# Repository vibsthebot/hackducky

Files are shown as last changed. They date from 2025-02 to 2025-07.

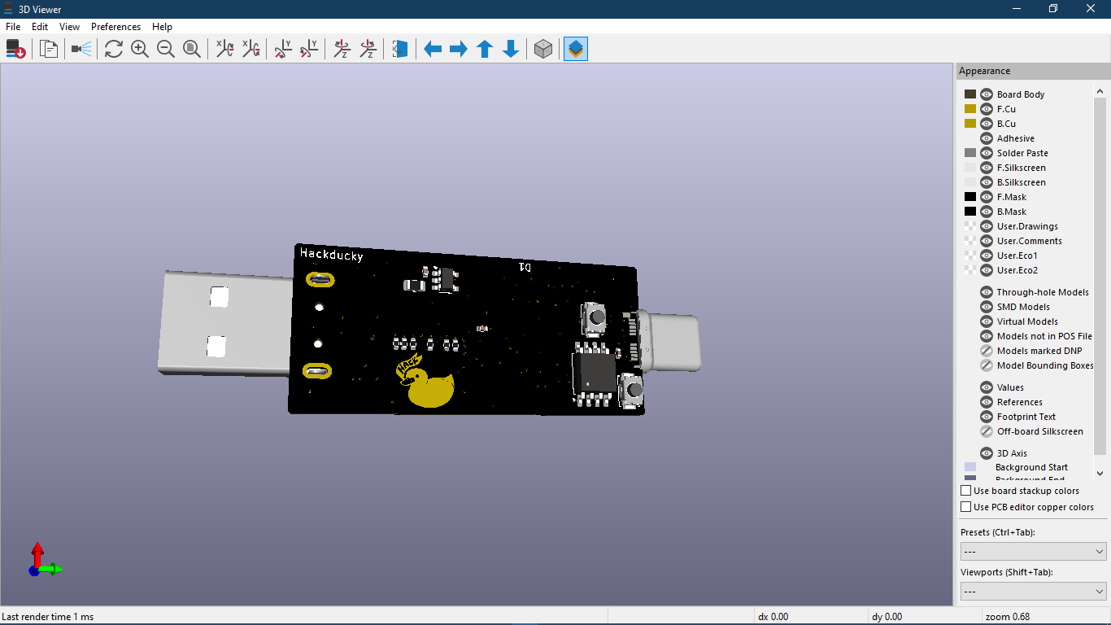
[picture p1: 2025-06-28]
pcb/v7/img/image.png

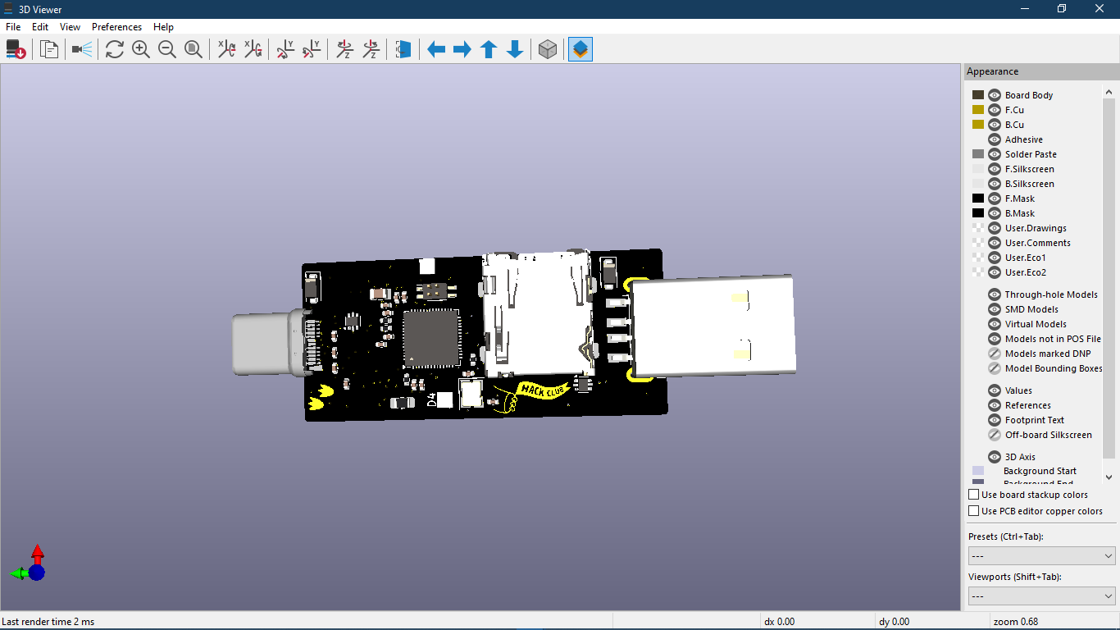
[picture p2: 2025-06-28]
pcb/v7/img/image-1.png

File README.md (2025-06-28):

# HackDucky - New YSWS!

The hackclub themed USB rubber ducky ! - Check out [hackducky](https://hackclub.slack.com/archives/C08B8HZBC85)

# What is this?

Hackducky is hackclubs own version of making a USB rubber ducky built by hackclubers.A usb rubber ducky is basically something that looks like a USB but is actually a trojan. It pretends to be a keyboard to the computer allowing you to basically take control of the computer you plug it into

## What you get

- Hackducky Board
    -  Dual USB ports (USB-A and USB-C)
    -  LED for the status - you can use it for other things if you like !
    -  Button for any extra features you may want to add !
    -  All duckyscripts are stored in the Hackduckys flash memory !

## Getting Started

1. - WIP

# Submission Criteria  

## 1. Time Requirement  
- **HackDucky Light:** Minimum of **3-4 hours** of development.  
- **HackDucky Pro:** Minimum of **5-6 hours** of development.  
- **Tracking:** Use **WakaTime** to track your development hours.  

## 2. Core Features (Must have 3)  
- Not just simple actions—core features should be impactful and unique.  
- **Examples:**  
  1. Open Notepad, start typing gibberish, and change the desktop background.  
  2. Open the terminal, run commands, and create pop-ups to scare the user.  
  3. Fake a system crash by downloading a **blue screen image** and freezing the mouse.  

## 3. Additional Features (Must have 5-7)  
- Include **at least 5-7 normal features** outside of the core features.  
- The more features, the better!  

## 4. Originality  
- Your project must be an **original idea** and not a direct copy from a tutorial.  
- Tutorials can be referenced, but your submission should be your own creation.  

## 5. Submission Limit  
- You can submit **multiple projects**, but you can only receive **one HackDucky** (either Pro or Light).  

## What the LED indicators mean

- Triple blink: Startup Sequence
- Single blink: Working/Processing - running/Starting Execution
- Rapid blinking: DuckyScript is incorrect / Firmware broke 😭 - Create a PR or new issue desribing the firmware problem

## Troubleshooting the LED's

1. LED rapidly blinking at startup:
 - Programming Mode
    - All is working great!
    - Its meant to blink rapidly in this mode
 - Payload Mode
       - Something is wrong with your duckyscript
       - Something is wrong with the firmware ( Create an Issue! )

3. Script not running:
   - Check script syntax
   - Verify file is properly saved
   - Try reformatting MicroSD card

4. Keyboard not recognized:
   - Try different USB port
   - Check USB connection
   - Verify target system supports USB HID

## Safety Notes

- pls dont hack people with this pls - its only ethical

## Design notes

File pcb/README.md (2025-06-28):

# 🦆 HackDucky

HackDucky is a compact, powerful RP2040-based USB device inspired by the concept of a "USB Rubber Ducky" — but fully open-source and customizable. It features dual USB ports (Type-A & Type-C), RGB status indicator, SD card support, and a generous 16MB flash. Ideal for scripting, automation, HID emulation, and more!

## 🔧 Features

* **RP2040 Microcontroller** – Dual-core Arm Cortex-M0+ @ 133MHz
* **16MB Flash** – Plenty of room for Ducky scripts, firmware, and more
* **USB-C & USB-A Ports** – Plug into any host device with ease
* **Micro SD Card Slot** – Store payloads, logs, or configs externally
* **RGB Neopixel** – Visual feedback for status, payload execution, etc
* **Compact Custom PCB** – Designed with portability and DIY hacking in mind

## 🧠 What Can It Do?

* Act as a USB HID device (keyboard/mouse automation)
* Emulate serial or mass storage devices
* Read payloads from SD card and execute them
* Light up RGB based on execution state (idle, running, error)
* Load firmware like CircuitPython, TinyUSB, or custom UF2 payloads

## 💻 Getting Started

1. **Flash Firmware**
   Connect via USB and flash with your favorite firmware (e.g. CircuitPython, Raspberry Pi Pico SDK UF2, etc).

2. **Insert SD Card (Optional)**
   Load your payloads/scripts/configs on a FAT32-formatted card.

3. **Connect to Host via USB-A**
   HackDucky will start executing its payload or HID script automatically (depending on firmware).

4. **RGB Status LED**

## ⚡ Power & USB Notes

* Use **USB-C & USB-A for power and flashing**

## 🧰 Tools Used

* KiCad for PCB Design
* RP2040 SDK / CircuitPython
* Open-source hardware and firmware philosophy

## 📸 Preview
Coming Soon
## 🔐 Disclaimer

This device is for **educational and ethical hacking purposes only**. Use responsibly. The creators is not responsible for any misuse.

---

## 📫 Connect

Built with ❤️ by [Souptik Samanta](https://souptik.me) & [Aarav Jhamb](https://github.com/The-UnknownHacker)

GitHub: [@souptik-samanta](https://github.com/souptik-samanta) & [Aarav Jhamb](https://github.com/The-UnknownHacker)
Instagram: [@souptik.me](https://instagram.com/souptik.me) & [Aarav Jhamb](aaravjhamb.com)
Hack Clubber & Hardware Hacker 💻🔌             Hack Clubber & Ethical Hacker 💻🔌

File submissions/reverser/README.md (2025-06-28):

# 🦆 Rubber Ducky Reverse Shell

**Author**: Aarav J  
**Payload**: Windows PowerShell Reverse Shell  
**Use**: For testing and educational use only.

---

## 💻 What it does

This script opens a **reverse shell** from the target computer to your listener using **PowerShell**.

Once plugged in, it:
- Hides the PowerShell window  
- Connects to your IP and port  
- Gives full remote shell access

---

## 🔧 How to use

1. **Start a listener** on your computer:
   ```
     nc -lvnp 4444
   ```

2. **Edit the payload**:  
   Replace `192.168.1.100` in the script with your local IP.

3. **Copy** the `.txt` file to the hackducky  

4. **Plug it into the target** and wait for the shell to connect back heheheh.

---

## ⚠️ Warning

This is for **educational use only**.  
Do **not** use this on any device you don’t own or have permission to test.

---

Screenshot of your script goes here

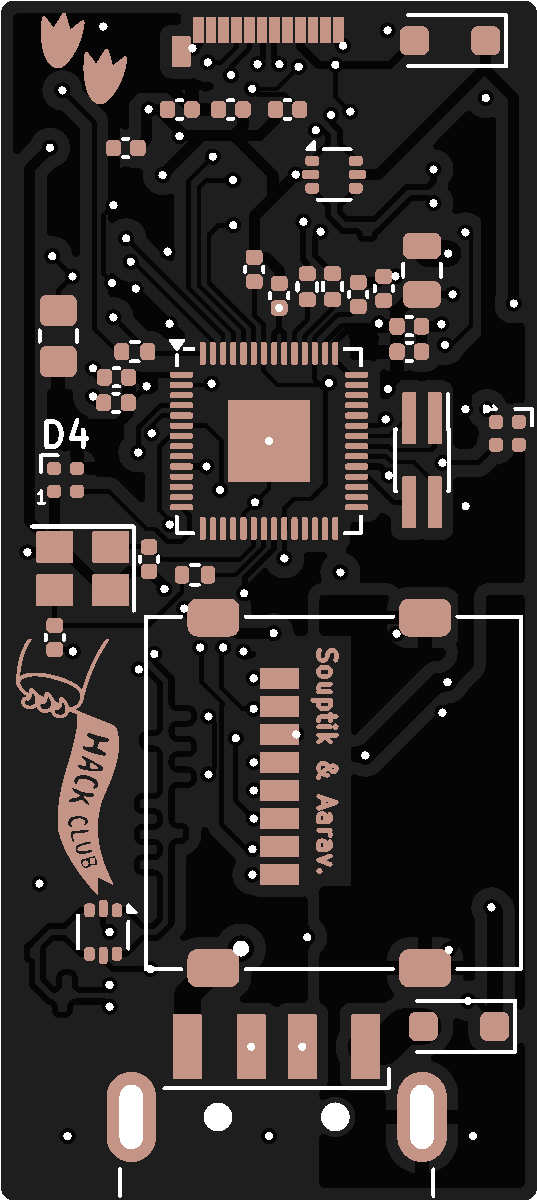
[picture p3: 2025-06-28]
pcb/v7/img/sm_black_top (1).png

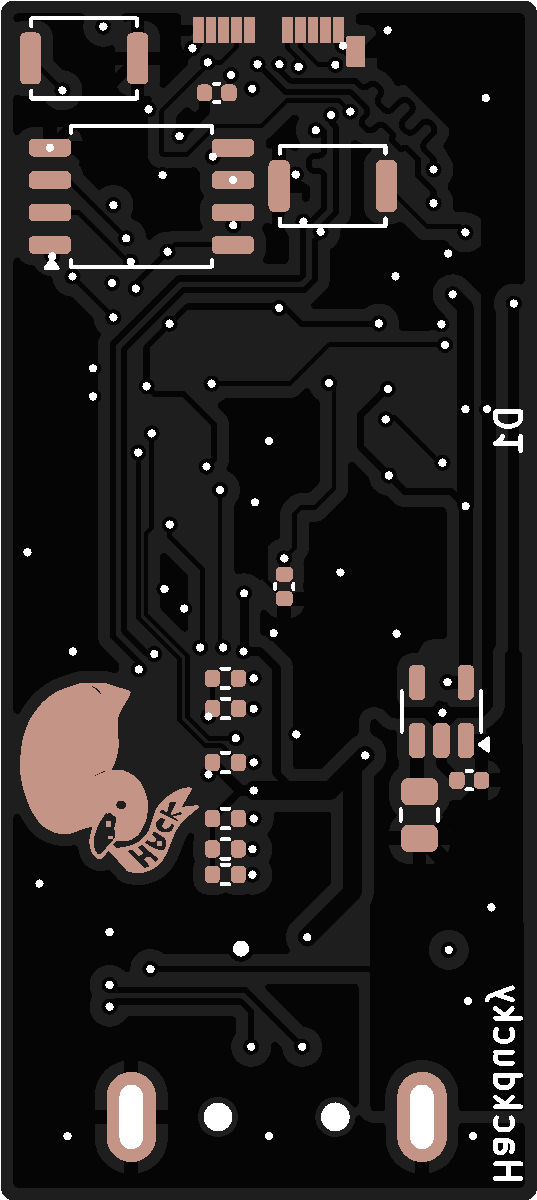
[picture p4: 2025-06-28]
pcb/v7/img/sm_black_bottom (1).png

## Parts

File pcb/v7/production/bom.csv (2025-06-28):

Designator | Footprint | Quantity | Value | LCSC Part #
C10, C14, C9 | 402 | 3 | 1uF | C52923
C11, C17, C18, C19, C20, C21, C7, C8 | 402 | 8 | 100nF | C1525
C12, C13 | 402 | 2 | 15pF
C15 | 805 | 1 | 1uF
C16, C22 | 402 | 2 | 100n
D1, D4 | LED_SK6812_EC15_1.5x1.5mm | 2 | WS2812B | C2909058
D2, D3 | D_SOD-123F | 2 | MBR1020VL | C191986
J1 | USB_A_CNCTech_1001-011-01101_Horizontal | 1 | USB_A | C136453
J2 | PinHeader_2x02_P1.00mm_Vertical_SMD | 1 | Conn_02x02_Top_Bottom
J3 | microSD_HC_Molex_47219-2001 | 1 | Micro_SD_Card | C164170
P2 | USB_C_Plug_Molex_105444 | 1 | USB_C_Plug | C3151751
R15 | 805 | 1 | DNF
R16, R17, R18, R19, R20, R21 | 402 | 6 | 10k | C191123
R22, R7 | 402 | 2 | 27.4 | C2076575
R4, R5 | 402 | 2 | 5.1K | C105872
R6 | 805 | 1 | 5.1K | C27834
R8, R9 | 402 | 2 | 1k | C242161
SW3, SW4 | SW_Push_SPST_NO_Alps_SKRK | 2 | BOOT_SEL | C202388
U1 | SOIC-8_5.3x5.3mm_P1.27mm | 1 | W25Q16JVSS | C131025
U2 | SOT-23-5 | 1 | AP2112K-3.3 | C23380830
U3, U5 | SOT-666 | 2 | USBLC6-2P6 | C2827693
U4 | QFN-56-1EP_7x7mm_P0.4mm_EP3.2x3.2mm | 1 | RP2040
Y1 | Crystal_SMD_Abracon_ABM8G-4Pin_3.2x2.5mm | 1 | Crystal_GND24 | C276421

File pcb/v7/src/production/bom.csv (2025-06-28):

Designator | Footprint | Quantity | Value | LCSC Part #
C10, C14, C9 | 0402 | 3 | 1uF
C11, C17, C18, C19, C20, C21, C7, C8 | 0402 | 8 | 100nF
C12, C13 | 0402 | 2 | 15pF
C15 | 0805 | 1 | 1uF
C16, C22 | 0402 | 2 | 100n
D1, D4 | LED_SK6812_EC15_1.5x1.5mm | 2 | WS2812B
D2, D3 | D_SOD-123F | 2 | MBR1020VL
J1 | USB_A_CNCTech_1001-011-01101_Horizontal | 1 | USB_A
J2 | PinHeader_2x02_P1.00mm_Vertical_SMD | 1 | Conn_02x02_Top_Bottom
J3 | microSD_HC_Hirose_DM3AT-SF-PEJM5 | 1 | Micro_SD_Card
P2 | USB_C_Plug_Molex_105444 | 1 | USB_C_Plug
R15 | 0805 | 1 | DNF
R16, R17, R18, R19, R20, R21 | 0402 | 6 | 10k
R22, R7 | 0402 | 2 | 27.4
R4, R5 | 0402 | 2 | 5.1K
R6 | 0805 | 1 | 5.1K
R8, R9 | 0402 | 2 | 1k
SW3, SW4 | SW_Push_SPST_NO_Alps_SKRK | 2 | BOOT_SEL | C318884
U1 | SOIC-8_5.3x5.3mm_P1.27mm | 1 | W25Q16JVSS
U2 | SOT-23-5 | 1 | AP2112K-3.3
U3, U5 | SOT-666 | 2 | USBLC6-2P6
U4 | QFN-56-1EP_7x7mm_P0.4mm_EP3.2x3.2mm | 1 | RP2040
Y1 | Crystal_SMD_Abracon_ABM8G-4Pin_3.2x2.5mm | 1 | Crystal_GND24

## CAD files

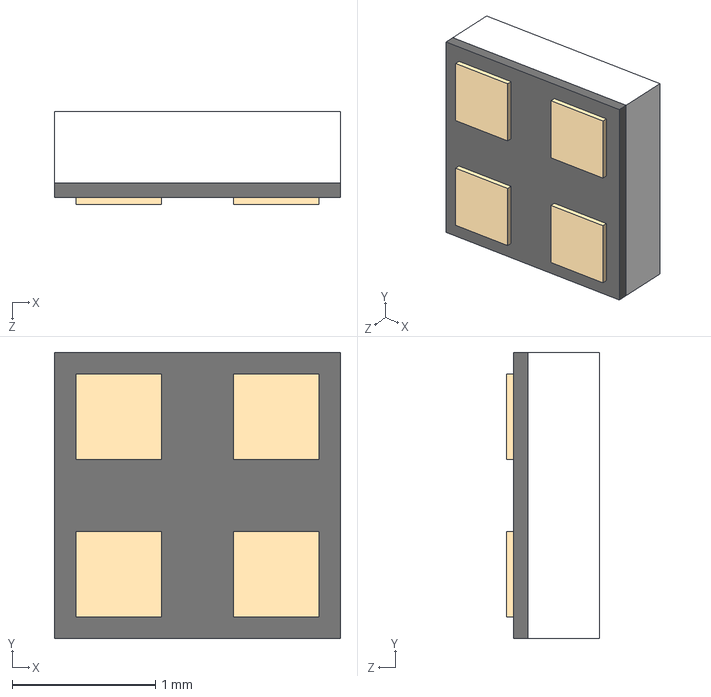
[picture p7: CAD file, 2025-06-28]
pcb/v7/src/models/SK6812-EC20.STEP
2.00 x 2.00 x 0.65 mm

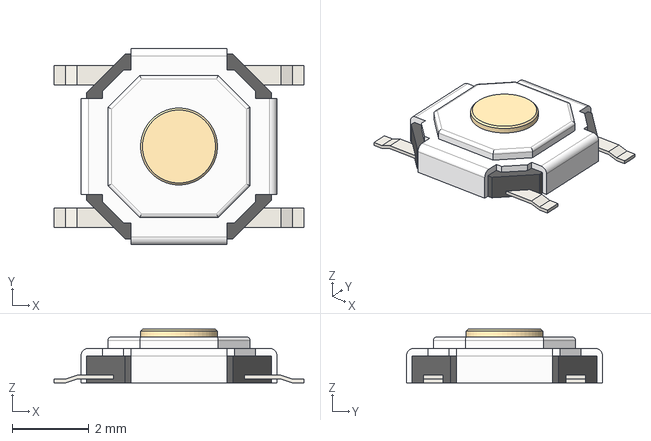
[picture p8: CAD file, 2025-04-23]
pcb/v7/src/models/TS-1187A.step
6.50 x 5.10 x 1.40 mm

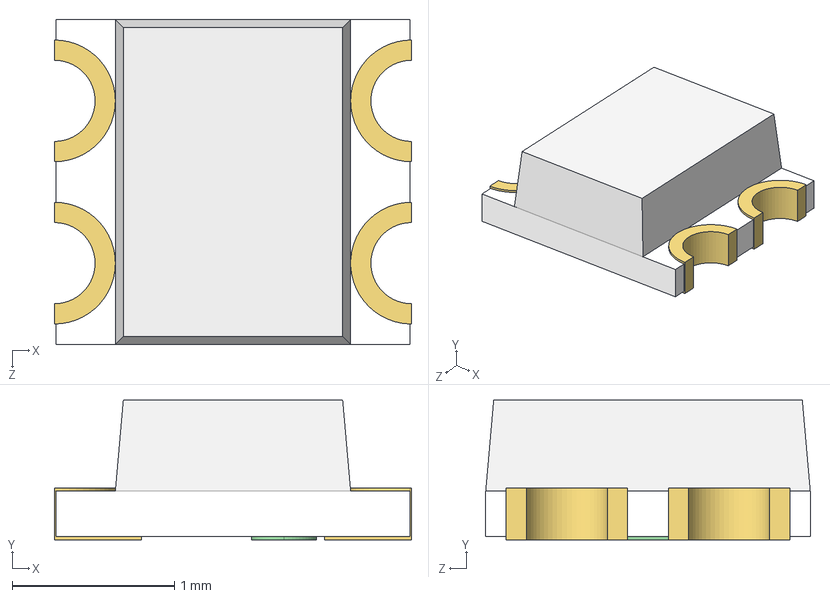
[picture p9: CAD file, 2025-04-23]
pcb/v7/src/models/WS2812-2020.STEP
2.20 x 0.86 x 2.00 mm

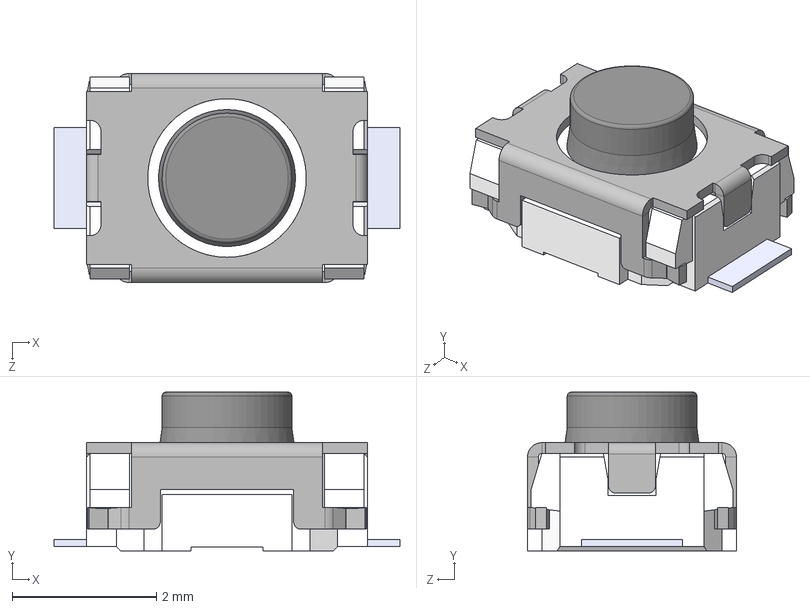
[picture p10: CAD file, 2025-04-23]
pcb/v7/src/models/SKRKAHE020--3DModel-STEP-56544.STEP
4.80 x 2.20 x 2.90 mm

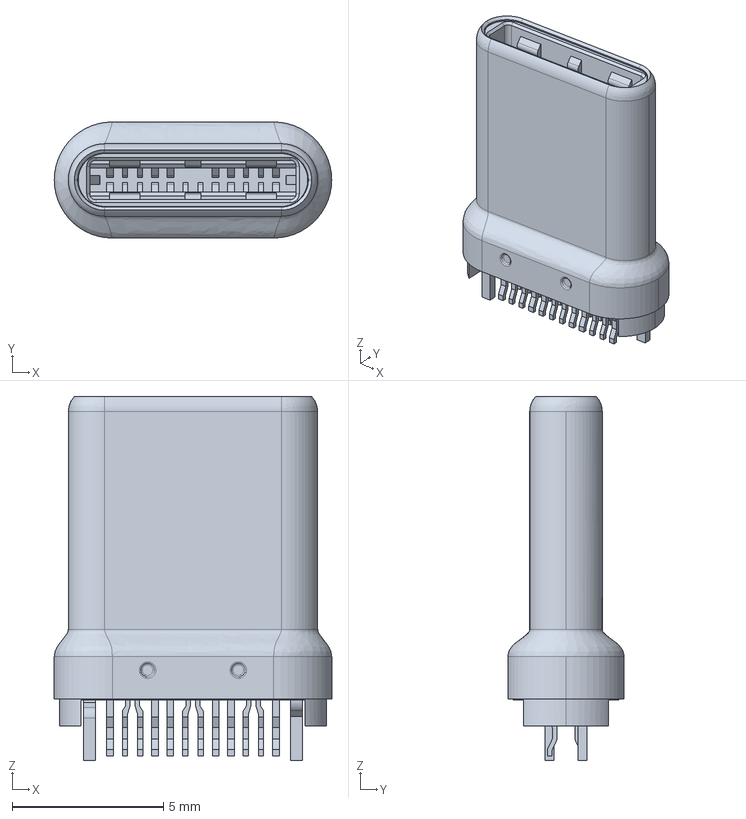
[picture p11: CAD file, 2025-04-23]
pcb/v7/src/models/1054440011.stp
9.18 x 3.84 x 12.0 mm

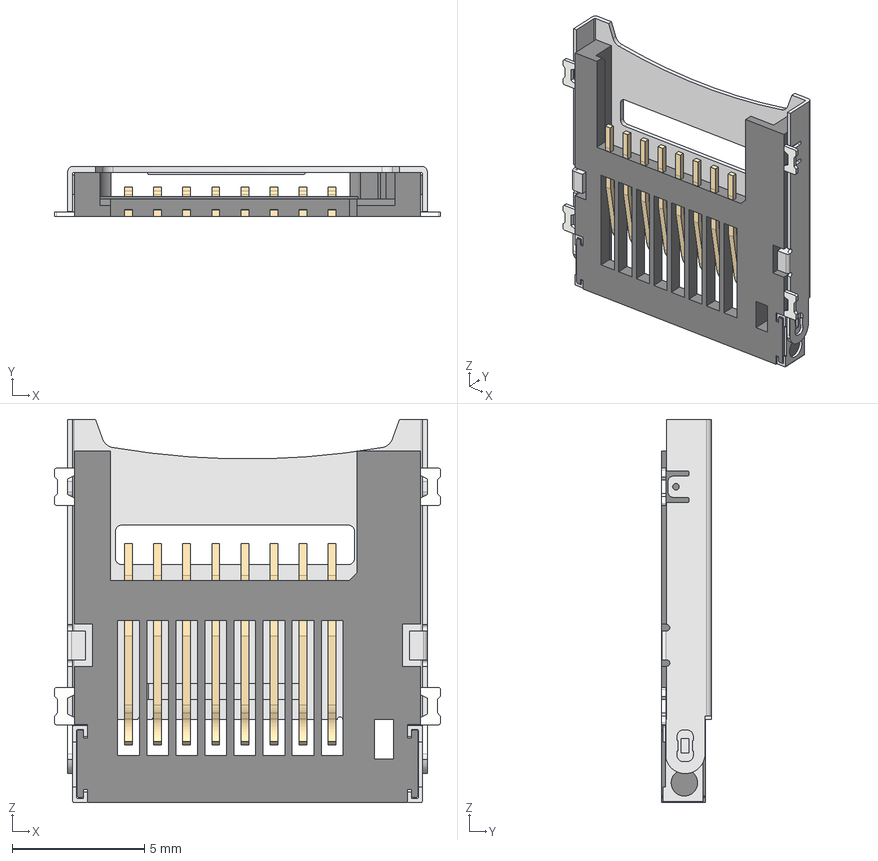
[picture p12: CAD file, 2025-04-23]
pcb/v7/src/models/472192001 v1.step
14.6 x 1.90 x 14.5 mm
Pins
Mounting
Cover
Hinge

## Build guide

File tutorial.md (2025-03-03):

# do you have or want a hackducky, here are the basics!

Welcome, have you ever wanted to plug in a USB drive to someones computer and take control, Well this is the perfect YSWS for you! Read On

---

## 🛠️ Step 1: Understanding the Basics
The hackducky uses a scripting language similar to duckyscript called hackscript. Its not really much of a difference, aside from hackscript having a few more features allowing you to control your hackducky more.

Every script follows a basic structure:
- **REM**: Comments for humans, ignored by the duck.
- **DEFAULT_DELAY**: Controls the speed of execution.
- **DELAY**: Pauses between actions (milliseconds).
- **STRING**: Types out text like a human.
- **GUI, CTRL, ALT**: Modifier keys for shortcuts.
- **ENTER**: Simulates pressing Enter.

Let's see it in action. This simple script opens Notepad, types a message, and saves the file:

```ducky
REM Basic example script
DEFAULT_DELAY 200

REM Open Run dialog
GUI r
DELAY 500

REM Launch Notepad
STRING notepad
ENTER
DELAY 1000

REM Type some text
STRING Hello from HackDucky!
ENTER

REM Save the file
CTRL s
STRING test.txt
ENTER
ALT F4
```

💡 **What’s happening here?**
- `GUI r` opens the Run dialog.
- `STRING notepad` types “notepad” and hits Enter.
- `STRING Hello from HackDucky!` types a message.
- `CTRL s` saves the file as "test.txt".
- `ALT F4` closes Notepad.

Boom! You just automated opening Notepad and saving a file. 🎉

---

## 🔢 Step 2: Variables and Loops
Want to make your scripts smarter? Use **variables** and **loops**!

### 🔄 Example: Counting to 5
```ducky
VAR counter 0
WHILE $counter < 5
    SET counter $counter + 1
    STRING Count: $counter
    ENTER
END_WHILE
```

💡 **What’s happening?**
- `VAR counter 0` creates a variable.
- `WHILE $counter < 5` loops while counter is less than 5.
- `SET counter $counter + 1` increases the counter.
- `STRING Count: $counter` types the current count.

Run this, and watch it type "Count: 1", "Count: 2"... up to 5! 🚀

---

## 🛠️ Step 3: Using Functions
Want to reuse some code? Functions make it easy.

### 📢 Example: Printing a Header
```ducky
FUNCTION PRINT_HEADER
    STRING ==================
    ENTER
    STRING = System Report =
    ENTER
    STRING ==================
    ENTER
END_FUNCTION

CALL PRINT_HEADER
```

💡 **What’s happening?**
- `FUNCTION PRINT_HEADER` creates a reusable block of code.
- `CALL PRINT_HEADER` runs it whenever needed.
- This prints a neat section header for reports.

---

## 🎯 What’s Next?  

Now you know the basics—time to experiment! Try making:  

✅ **A script that opens a website and types a message**  
✅ **A prank script that rickroles someone as soon as you plug in the usb**  
✅ **A function that automates logins**  
✅ **A script that runs Doom in the terminal!** – *Interesting, I see.*  

### ⚡ Pro Tips:
- Start simple, then add more features.
- Use `DELAY` wisely—too fast and your computer might miss keystrokes.
- Have fun!

Drop your creations in the #hackducky channel on the hack club slack, and let's see what you build! 🛠️🔥

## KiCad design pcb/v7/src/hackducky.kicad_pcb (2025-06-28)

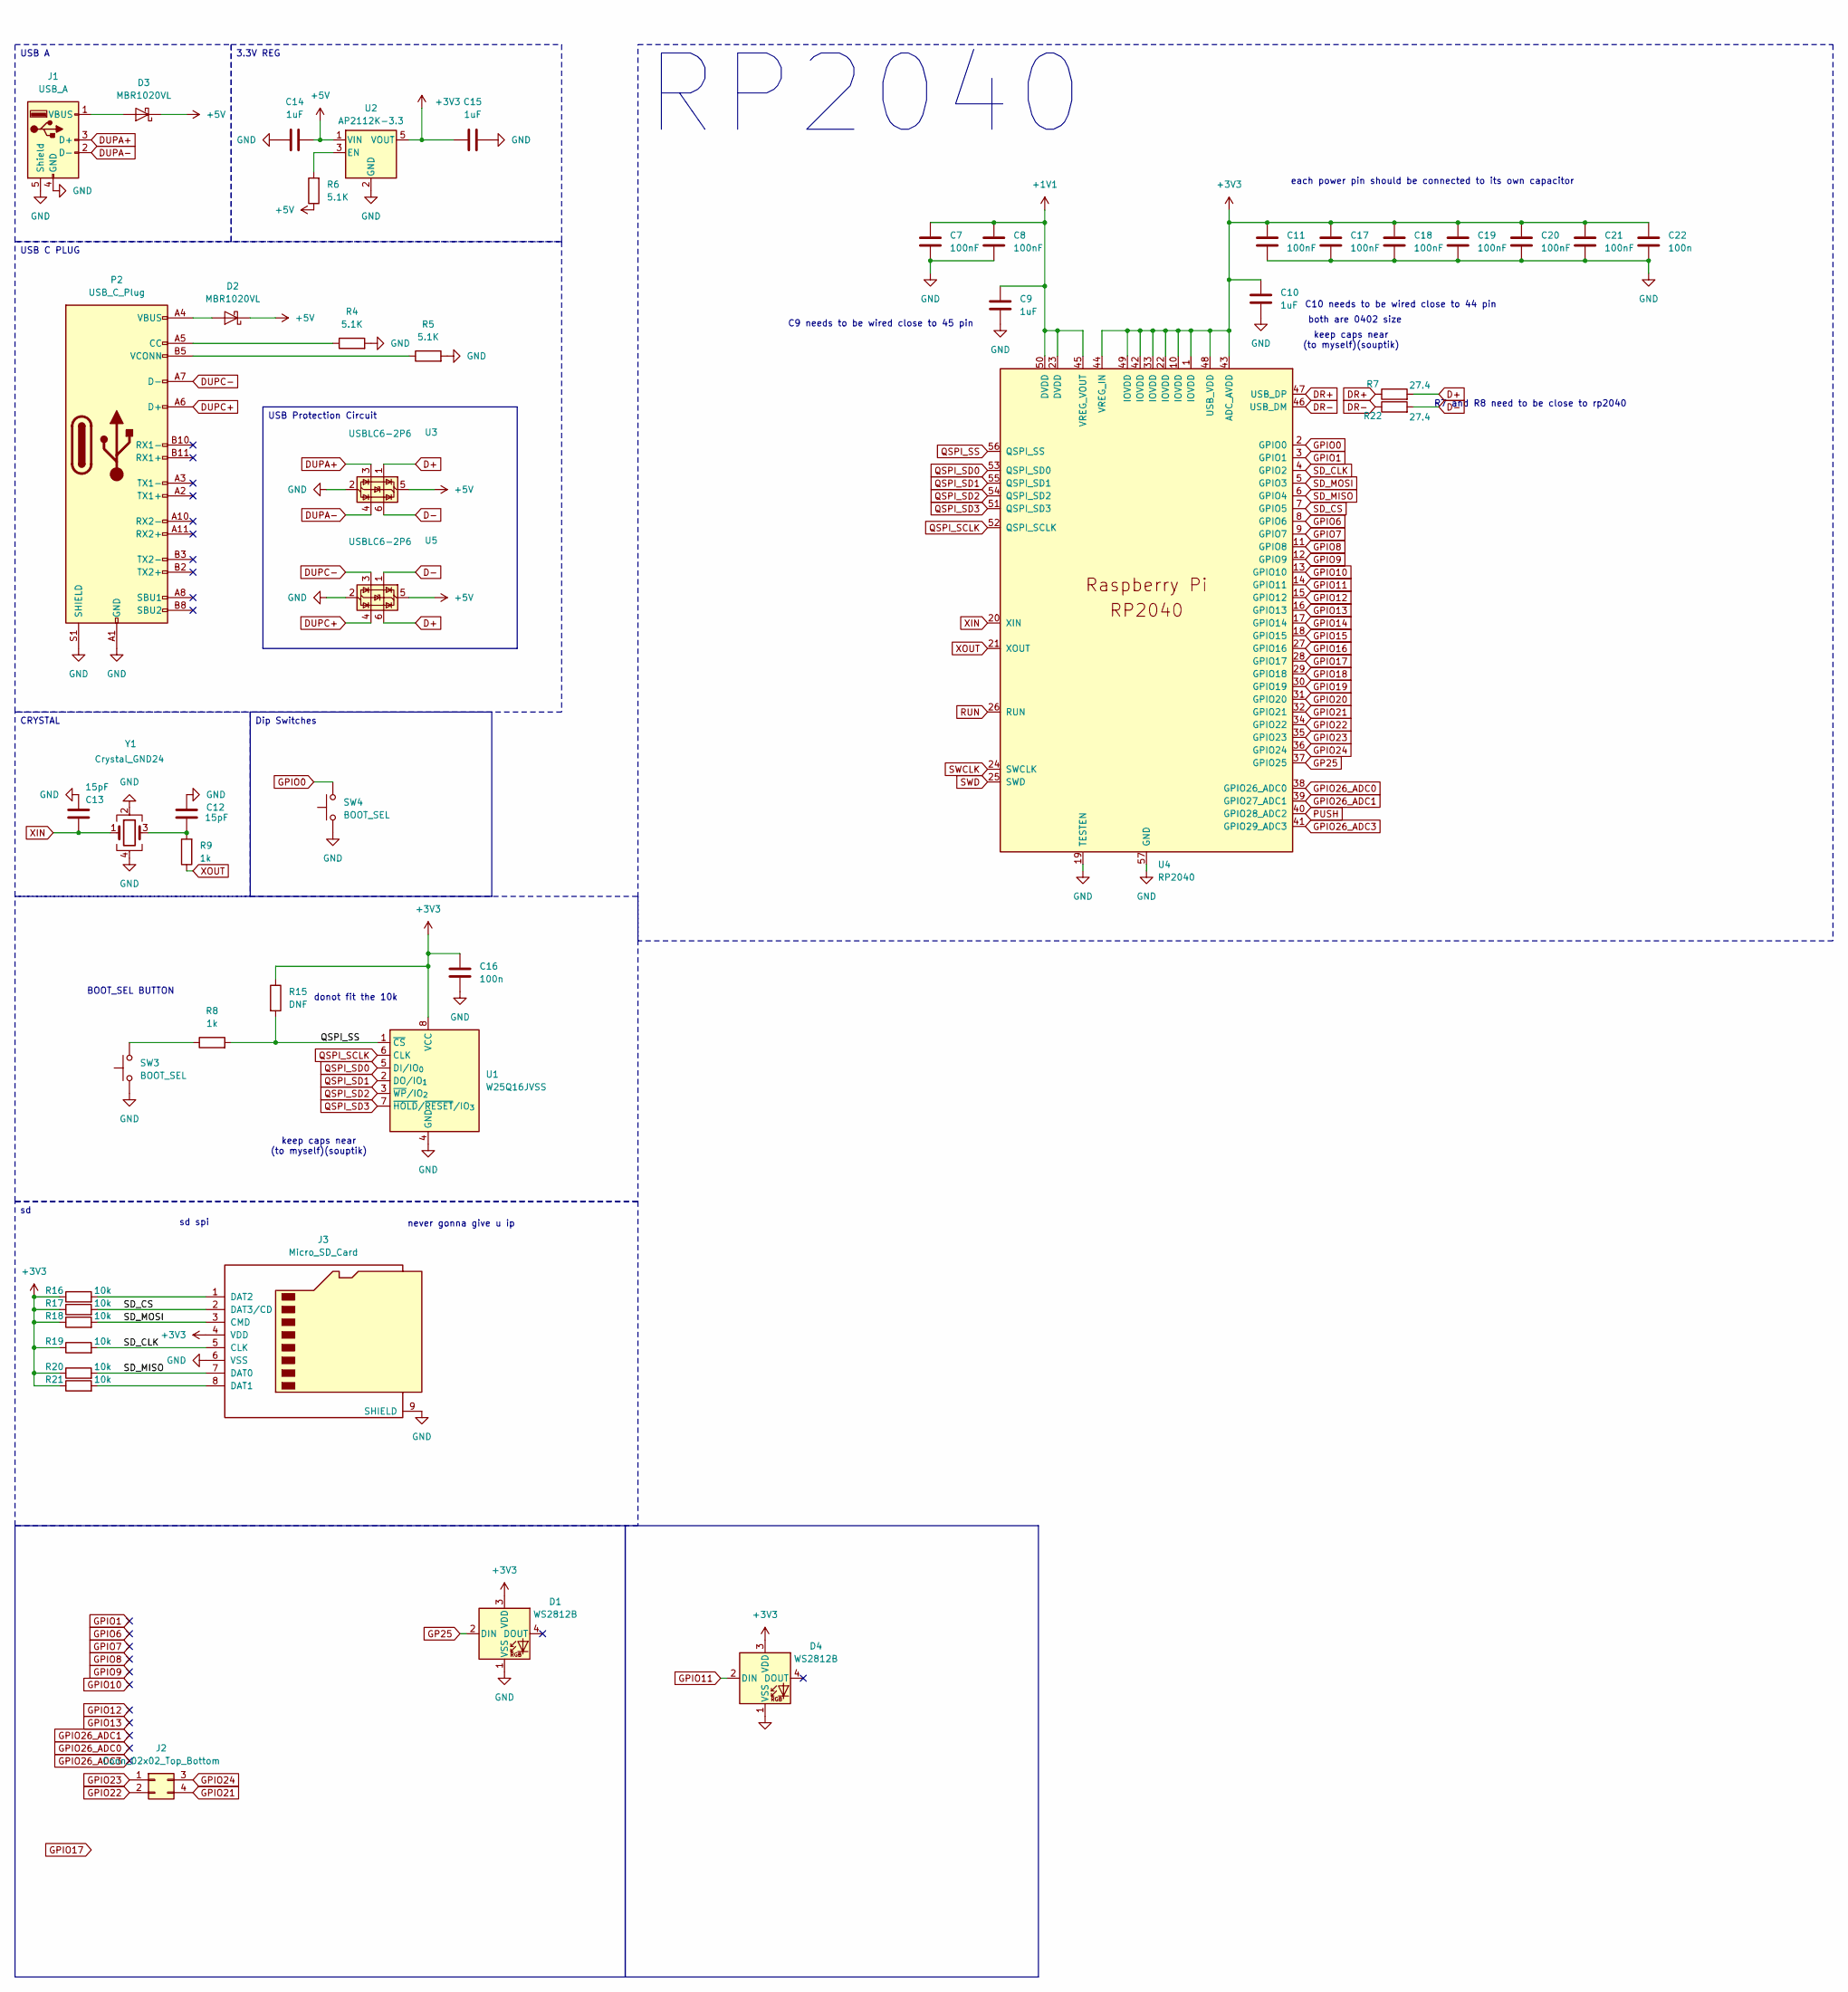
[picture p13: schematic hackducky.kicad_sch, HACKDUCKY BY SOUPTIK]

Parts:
C7, C8, C11, C17, C18, C19, C20, C21: 100nF; C_0402_1005Metric
C9, C10, C14: 1uF; C_0402_1005Metric
C12, C13: 15pF; C_0402_1005Metric
C15: 1uF; C_0805_2012Metric
C16, C22: 100n; C_0402_1005Metric
D1, D4: WS2812B; LED_SK6812_EC15_1.5x1.5mm
D2, D3: MBR1020VL; D_SOD-123F
J1: USB_A; USB_A_CNCTech_1001-011-01101_Horizontal
J2: Conn_02x02_Top_Bottom; PinHeader_2x02_P1.00mm_Vertical_SMD
J3: Micro_SD_Card; microSD_HC_Hirose_DM3AT-SF-PEJM5
P2: USB_C_Plug; USB_C_Plug_Molex_105444
R4, R5: 5.1K; C_0402_1005Metric
R6: 5.1K; R_0805_2012Metric
R7, R22: 27.4; R_0402_1005Metric
R8, R9: 1k; R_0402_1005Metric
R15: DNF; R_0805_2012Metric_Pad1.20x1.40mm_HandSolder
R16, R17, R18, R19, R20, R21: 10k; R_0402_1005Metric
SW3, SW4: BOOT_SEL; SW_Push_SPST_NO_Alps_SKRK; LCSC C318884
U1: W25Q16JVSS; SOIC-8_5.3x5.3mm_P1.27mm
U2: AP2112K-3.3; SOT-23-5
U3, U5: USBLC6-2P6; SOT-666
U4: RP2040; QFN-56-1EP_7x7mm_P0.4mm_EP3.2x3.2mm
Y1: Crystal_GND24; Crystal_SMD_Abracon_ABM8G-4Pin_3.2x2.5mm

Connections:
+1V1: C7.1, C8.1, C9.1, U4.23 (DVDD), U4.45 (VREG_VOUT), U4.50 (DVDD)
+3V3: C10.1, C11.1, C15.2, C16.1, C17.1, C18.1, C19.1, C20.1, C21.1, C22.1, D1.3 (VDD), D4.3 (VDD), J3.4 (VDD), R15.1, R16.1, R17.1, R18.1, R19.1, R20.1, R21.1, U1.8 (VCC), U2.5 (VOUT), U4.1 (IOVDD), U4.10 (IOVDD), U4.22 (IOVDD), U4.33 (IOVDD), U4.42 (IOVDD), U4.43 (ADC_AVDD), U4.44 (VREG_IN), U4.48 (USB_VDD), U4.49 (IOVDD)
+5V: C14.1, D2.1 (K), D3.1 (K), R6.1, U2.1 (VIN), U3.5 (VBUS), U5.5 (VBUS)
D+: R7.2, U3.1 (I/O1), U5.6 (I/O1)
D-: R22.2, U3.6 (I/O1), U5.1 (I/O1)
DR+: R7.1, U4.47 (USB_DP)
DR-: R22.1, U4.46 (USB_DM)
DUPA+: J1.3 (D+), U3.3 (I/O2)
DUPA-: J1.2 (D-), U3.4 (I/O2)
DUPC+: P2.A6 (D+), U5.4 (I/O2)
DUPC-: P2.A7 (D-), U5.3 (I/O2)
GND: C7.2, C8.2, C9.2, C10.2, C11.2, C12.2, C13.2, C14.2, C15.1, C16.2, C17.2, C18.2, C19.2, C20.2, C21.2, C22.2, D1.1 (VSS), D4.1 (VSS), J1.4 (GND), J1.5 (Shield), J3.6 (VSS), J3.9 (SHIELD), P2.A1 (GND), P2.A12 (GND), P2.B1 (GND), P2.B12 (GND), P2.S1 (SHIELD), R4.2, R5.2, SW3.1, SW4.1, U1.4 (GND), U2.2 (GND), U3.2 (GND), U4.19 (TESTEN), U4.57 (GND), U5.2 (GND), Y1.2, Y1.4
GP25: D1.2 (DIN), U4.37 (GPIO25)
GPIO0: SW4.2, U4.2 (GPIO0)
GPIO1: U4.3 (GPIO1)
GPIO6: U4.8 (GPIO6)
GPIO7: U4.9 (GPIO7)
GPIO8: U4.11 (GPIO8)
GPIO9: U4.12 (GPIO9)
GPIO10: U4.13 (GPIO10)
GPIO11: D4.2 (DIN), U4.14 (GPIO11)
GPIO12: U4.15 (GPIO12)
GPIO13: U4.16 (GPIO13)
GPIO14: U4.17 (GPIO14)
GPIO15: U4.18 (GPIO15)
GPIO16: U4.27 (GPIO16)
GPIO17: U4.28 (GPIO17)
GPIO18: U4.29 (GPIO18)
GPIO19: U4.30 (GPIO19)
GPIO20: U4.31 (GPIO20)
GPIO21: J2.4, U4.32 (GPIO21)
GPIO22: J2.2, U4.34 (GPIO22)
GPIO23: J2.1, U4.35 (GPIO23)
GPIO24: J2.3, U4.36 (GPIO24)
GPIO26_ADC0: U4.38 (GPIO26_ADC0)
GPIO26_ADC1: U4.39 (GPIO27_ADC1)
GPIO26_ADC3: U4.41 (GPIO29_ADC3)
unnamed: C12.1, R9.2, Y1.3
unnamed: D2.2 (A), P2.A4 (VBUS), P2.A9 (VBUS), P2.B4 (VBUS), P2.B9 (VBUS)
unnamed: D3.2 (A), J1.1 (VBUS)
unnamed: J3.8 (DAT1), R21.2
unnamed: J3.1 (DAT2), R16.2
unnamed: P2.A5 (CC), R4.1
unnamed: P2.B5 (VCONN), R5.1
unnamed: R8.1, SW3.2
unnamed: R6.2, U2.3 (EN)
PUSH: U4.40 (GPIO28_ADC2)
QSPI_SCLK: U1.6 (CLK), U4.52 (QSPI_SCLK)
QSPI_SD0: U1.5 (DI/IO_{0}), U4.53 (QSPI_SD0)
QSPI_SD1: U1.2 (DO/IO_{1}), U4.55 (QSPI_SD1)
QSPI_SD2: U1.3 (~WP/IO_{2}), U4.54 (QSPI_SD2)
QSPI_SD3: U1.7 (~HOLD/~RESET/IO_{3}), U4.51 (QSPI_SD3)
QSPI_SS: R8.2, R15.2, U1.1 (~CS), U4.56 (QSPI_SS)
RUN: U4.26 (RUN)
SD_CLK: J3.5 (CLK), R19.2, U4.4 (GPIO2)
SD_CS: J3.2 (DAT3/CD), R17.2, U4.7 (GPIO5)
SD_MISO: J3.7 (DAT0), R20.2, U4.6 (GPIO4)
SD_MOSI: J3.3 (CMD), R18.2, U4.5 (GPIO3)
SWCLK: U4.24 (SWCLK)
SWD: U4.25 (SWD)
XIN: C13.1, U4.20 (XIN), Y1.1
XOUT: R9.1, U4.21 (XOUT)

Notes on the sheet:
sd spi
C9 needs to be wired close to 45 pin
keep caps near (to myself)(souptik)
donot fit the 10k
R7 and R8 need to be close to rp2040
C10 needs to be wired close to 44 pin
BOOT_SEL BUTTON
never gonna give u ip
both are 0402 size
each power pin should be connected to its own capacitor
CRYSTAL
RP2040
USB Protection Circuit
USB C PLUG
Dip Switches
3.3V REG
USB A

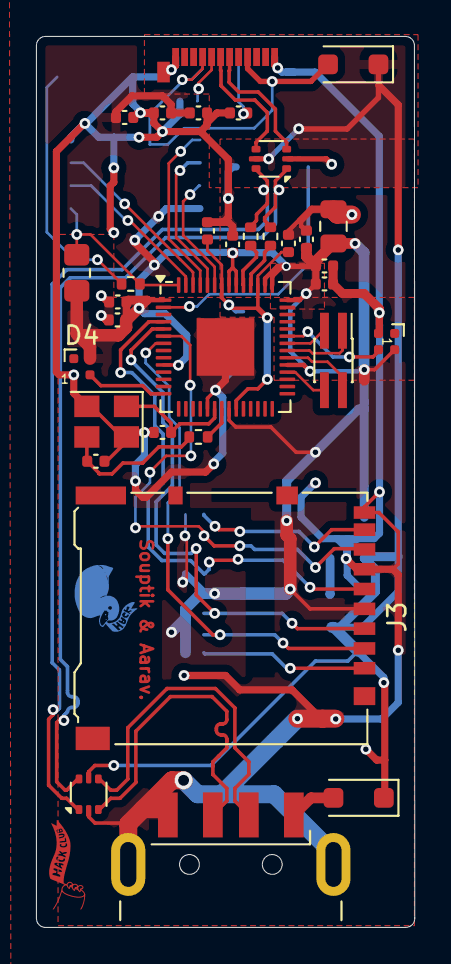
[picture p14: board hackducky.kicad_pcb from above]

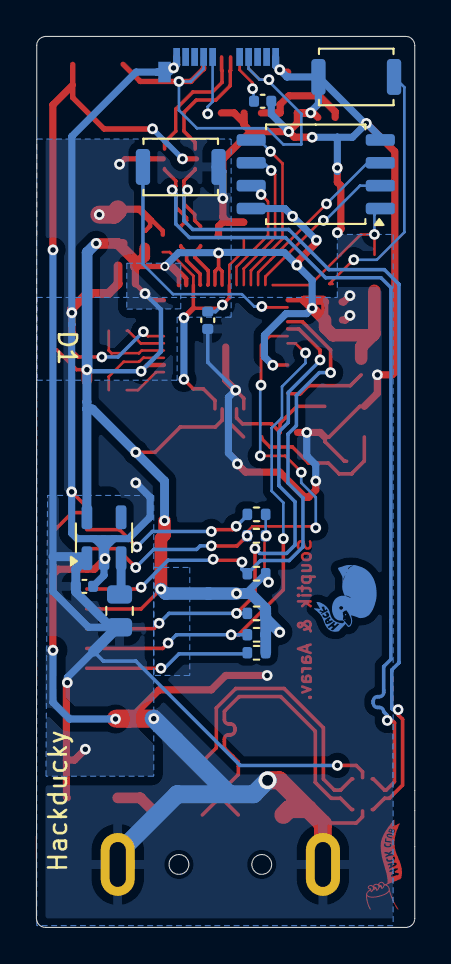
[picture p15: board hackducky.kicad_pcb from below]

Board: 2 copper layers, 21.0 x 49.5 mm, 46 parts (14 on the bottom side), 40 nets.

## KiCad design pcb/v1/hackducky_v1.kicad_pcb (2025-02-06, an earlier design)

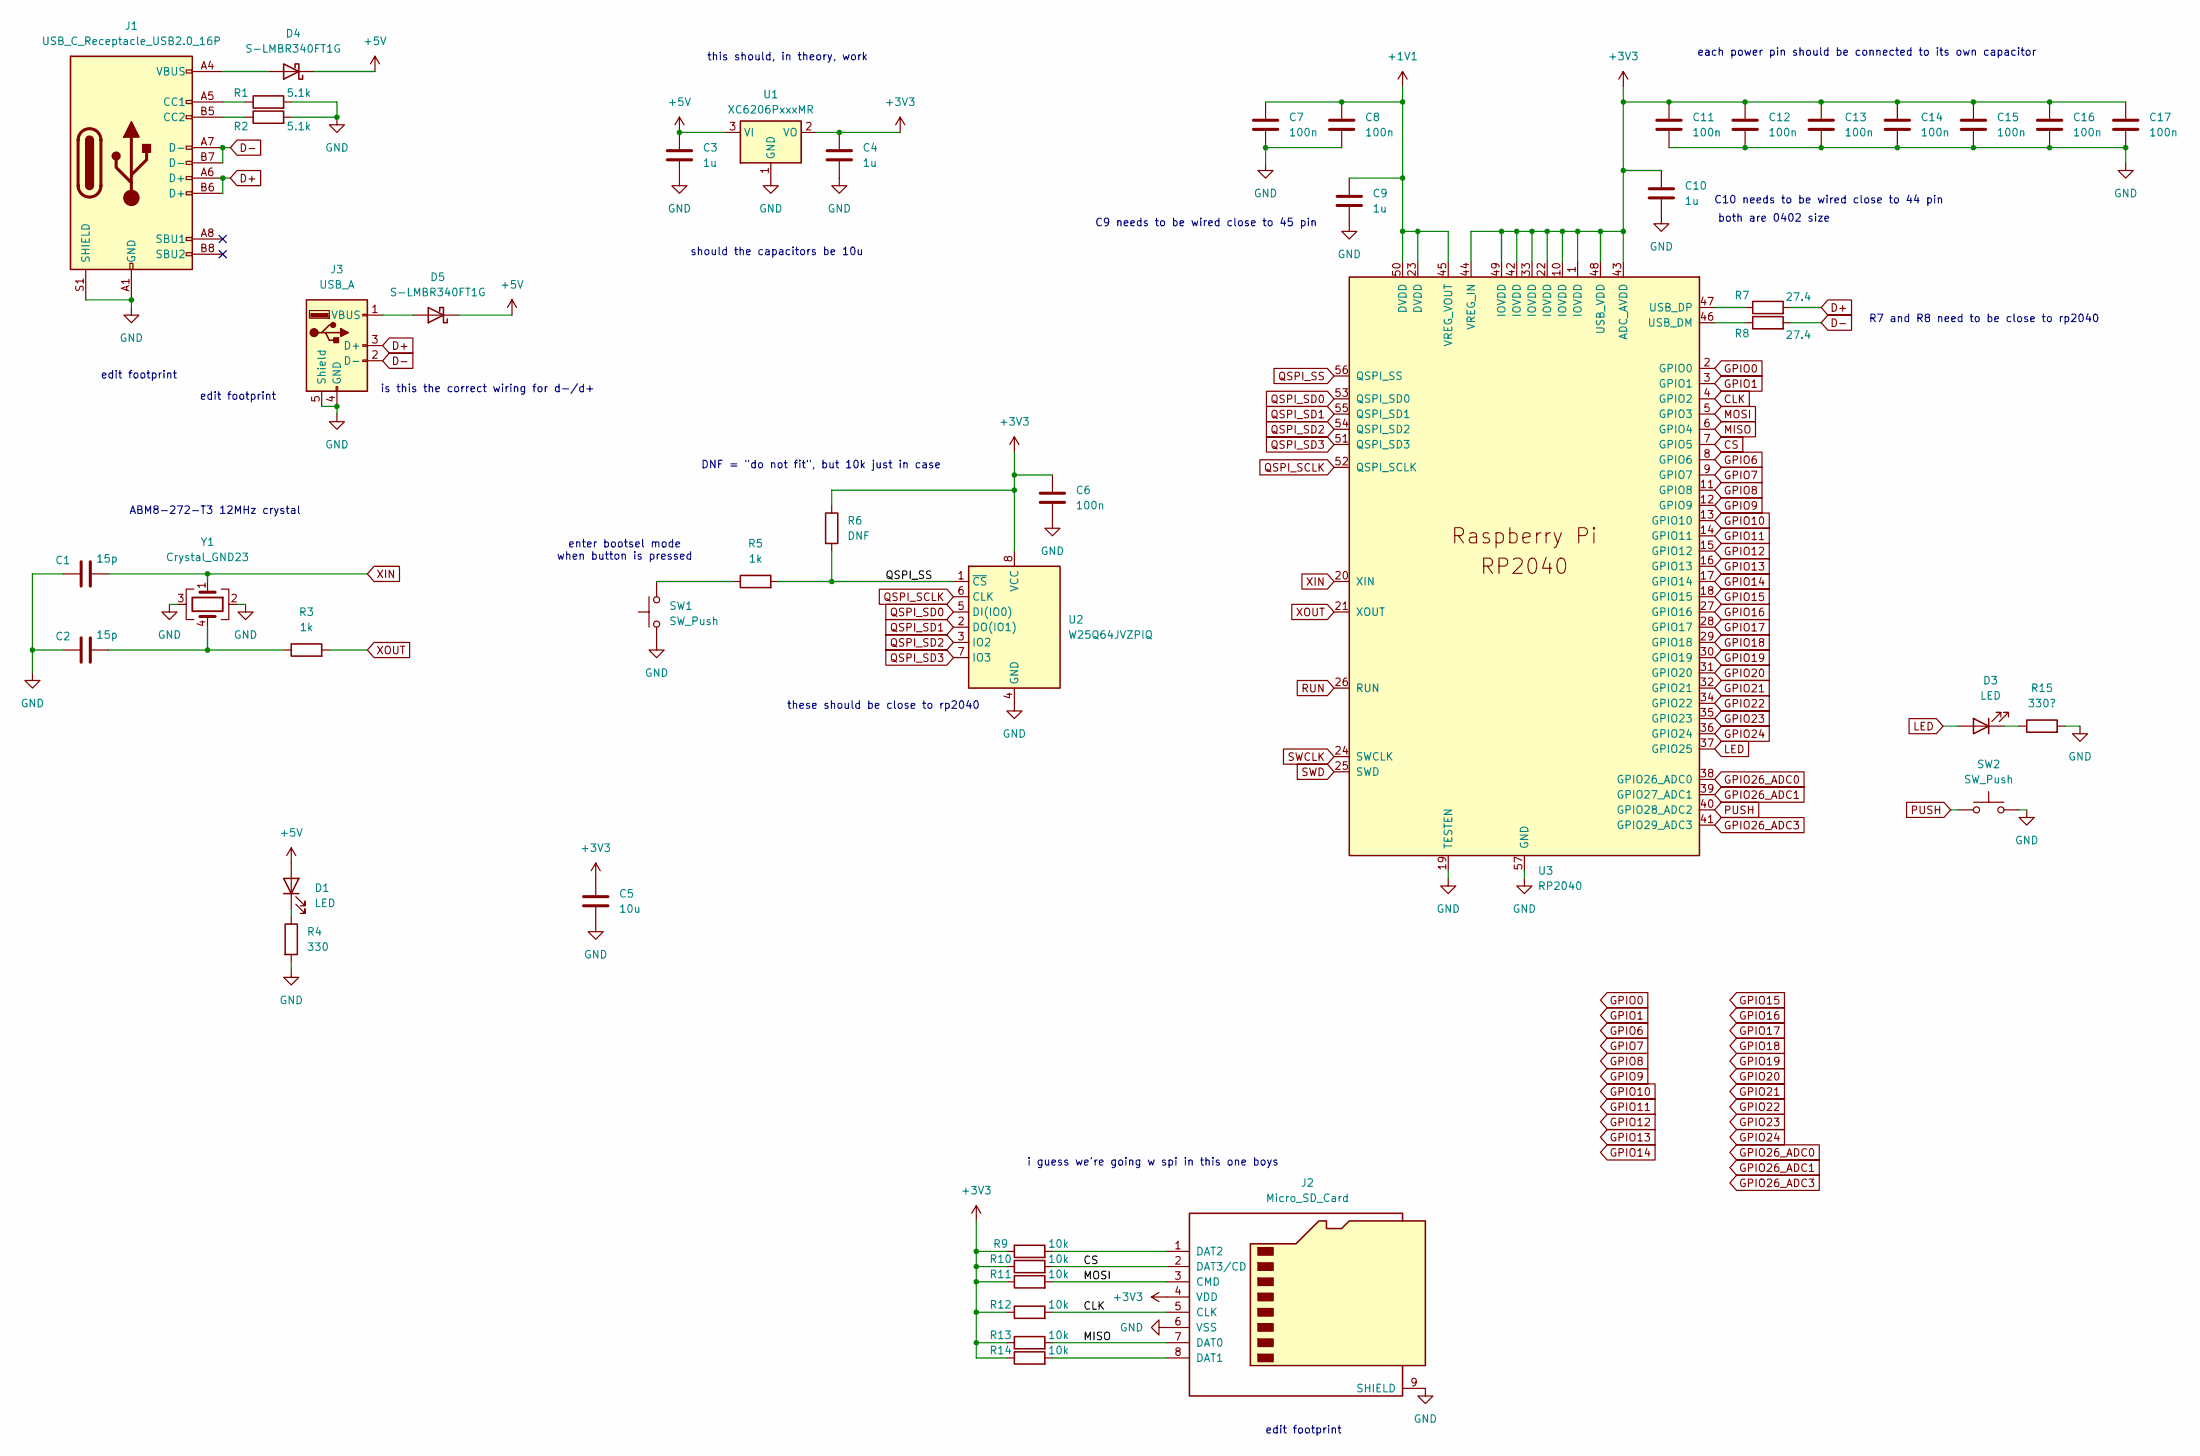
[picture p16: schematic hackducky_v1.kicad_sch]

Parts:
C1, C2: 15p; C_0402_1005Metric
C3, C4, C9, C10: 1u; C_0402_1005Metric
C5: 10u; C_0402_1005Metric
C6, C7, C8, C11, C12, C13, C14, C15, C16, C17: 100n; C_0402_1005Metric
D1: LED; LED_0805_2012Metric
D3: LED; LED_0402_1005Metric
D4, D5: S-LMBR340FT1G; D_0805_2012Metric
J1: USB_C_Receptacle_USB2.0_16P; USB_C_Plug_Molex_105444
J2: Micro_SD_Card; microSD_HC_Molex_47219-2001
J3: USB_A; USB3_A_Plug_Wuerth_692112030100_Horizontal
R1, R2: 5.1k; R_0402_1005Metric
R3, R5: 1k; R_0402_1005Metric
R4: 330; R_0402_1005Metric
R6: DNF; R_0402_1005Metric
R7, R8: 27.4; R_0402_1005Metric
R9, R10, R11, R12, R13, R14: 10k; R_0402_1005Metric
R15: 330?; R_0402_1005Metric
SW1: SW_Push; SW_Push_1P1T_XKB_TS-1187A; LCSC C318884
SW2: SW_Push; SW_PUSH_6mm
U1: XC6206PxxxMR; SOT-23-3
U2: W25Q64JVZPIQ; WSON-8-1EP_6x5mm_P1.27mm_EP3.4x4mm
U3: RP2040; QFN-56-1EP_7x7mm_P0.4mm_EP3.2x3.2mm
Y1: Crystal_GND23; Crystal_SMD_Abracon_ABM8G-4Pin_3.2x2.5mm

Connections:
+1V1: C7.1, C8.1, C9.1, U3.23 (DVDD), U3.45 (VREG_VOUT), U3.50 (DVDD)
+3V3: C4.1, C5.1, C6.1, C10.1, C11.1, C12.1, C13.1, C14.1, C15.1, C16.1, C17.1, J2.4 (VDD), R6.1, R9.1, R10.1, R11.1, R12.1, R13.1, R14.1, U1.2 (VO), U2.8 (VCC), U3.1 (IOVDD), U3.10 (IOVDD), U3.22 (IOVDD), U3.33 (IOVDD), U3.42 (IOVDD), U3.43 (ADC_AVDD), U3.44 (VREG_IN), U3.48 (USB_VDD), U3.49 (IOVDD)
+5V: C3.1, D1.2 (A), D4.1 (K), D5.1 (K), U1.3 (VI)
CLK: J2.5 (CLK), R12.2, U3.4 (GPIO2)
CS: J2.2 (DAT3/CD), R10.2, U3.7 (GPIO5)
D+: J1.A6 (D+), J1.B6 (D+), J3.3 (D+), R7.2
D-: J1.A7 (D-), J1.B7 (D-), J3.2 (D-), R8.2
GND: C1.1, C2.1, C3.2, C4.2, C5.2, C6.2, C7.2, C8.2, C9.2, C10.2, C11.2, C12.2, C13.2, C14.2, C15.2, C16.2, C17.2, J1.A1 (GND), J1.A12 (GND), J1.B1 (GND), J1.B12 (GND), J1.S1 (SHIELD), J2.6 (VSS), J2.9 (SHIELD), J3.4 (GND), J3.5 (Shield), R1.2, R2.2, R4.2, R15.2, SW1.1, SW2.2, U1.1 (GND), U2.4 (GND), U3.19 (TESTEN), U3.57 (GND), Y1.2, Y1.3
GPIO0: U3.2 (GPIO0)
GPIO1: U3.3 (GPIO1)
GPIO6: U3.8 (GPIO6)
GPIO7: U3.9 (GPIO7)
GPIO8: U3.11 (GPIO8)
GPIO9: U3.12 (GPIO9)
GPIO10: U3.13 (GPIO10)
GPIO11: U3.14 (GPIO11)
GPIO12: U3.15 (GPIO12)
GPIO13: U3.16 (GPIO13)
GPIO14: U3.17 (GPIO14)
GPIO15: U3.18 (GPIO15)
GPIO16: U3.27 (GPIO16)
GPIO17: U3.28 (GPIO17)
GPIO18: U3.29 (GPIO18)
GPIO19: U3.30 (GPIO19)
GPIO20: U3.31 (GPIO20)
GPIO21: U3.32 (GPIO21)
GPIO22: U3.34 (GPIO22)
GPIO23: U3.35 (GPIO23)
GPIO24: U3.36 (GPIO24)
GPIO26_ADC0: U3.38 (GPIO26_ADC0)
GPIO26_ADC1: U3.39 (GPIO27_ADC1)
GPIO26_ADC3: U3.41 (GPIO29_ADC3)
LED: D3.2 (A), U3.37 (GPIO25)
MISO: J2.7 (DAT0), R13.2, U3.6 (GPIO4)
MOSI: J2.3 (CMD), R11.2, U3.5 (GPIO3)
unnamed: C2.2, R3.1, Y1.4
unnamed: D1.1 (K), R4.1
unnamed: D3.1 (K), R15.1
unnamed: D4.2 (A), J1.A4 (VBUS), J1.A9 (VBUS), J1.B4 (VBUS), J1.B9 (VBUS)
unnamed: D5.2 (A), J3.1 (VBUS)
unnamed: J1.A5 (CC1), R1.1
unnamed: J1.B5 (CC2), R2.1
unnamed: J2.8 (DAT1), R14.2
unnamed: J2.1 (DAT2), R9.2
unnamed: R5.1, SW1.2
unnamed: R8.1, U3.46 (USB_DM)
unnamed: R7.1, U3.47 (USB_DP)
PUSH: SW2.1, U3.40 (GPIO28_ADC2)
QSPI_SCLK: U2.6 (CLK), U3.52 (QSPI_SCLK)
QSPI_SD0: U2.5 (DI(IO0)), U3.53 (QSPI_SD0)
QSPI_SD1: U2.2 (DO(IO1)), U3.55 (QSPI_SD1)
QSPI_SD2: U2.3 (IO2), U3.54 (QSPI_SD2)
QSPI_SD3: U2.7 (IO3), U3.51 (QSPI_SD3)
QSPI_SS: R5.2, R6.2, U2.1 (~CS), U3.56 (QSPI_SS)
RUN: U3.26 (RUN)
SWCLK: U3.24 (SWCLK)
SWD: U3.25 (SWD)
XIN: C1.2, U3.20 (XIN), Y1.1
XOUT: R3.2, U3.21 (XOUT)

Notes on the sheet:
these should be close to rp2040
C9 needs to be wired close to 45 pin
is this the correct wiring for d-/d+
R7 and R8 need to be close to rp2040
this should, in theory, work
C10 needs to be wired close to 44 pin
should the capacitors be 10u
i guess we're going w spi in this one boys
both are 0402 size
edit footprint
each power pin should be connected to its own capacitor
enter bootsel mode when button is pressed
ABM8-272-T3 12MHz crystal
DNF = "do not fit", but 10k just in case

Board: 2 copper layers, 45 parts (0 on the bottom side), 32 nets, no tracks yet.

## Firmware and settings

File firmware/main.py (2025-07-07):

import board
import digitalio
import time
import usb_hid
import os

print("Main.py: Starting up...")
time.sleep(1)  # Reduced delay for testing

# Setup LED
status_led = digitalio.DigitalInOut(board.LED)
status_led.direction = digitalio.Direction.OUTPUT

def flash_error():
    while True:
        status_led.value = True
        time.sleep(0.1)
        status_led.value = False
        time.sleep(0.1)

# Initialize keyboard right away if we're in payload mode
try:
    print("Main.py: Checking USB HID devices...")
    if not usb_hid.devices:
        print("Main.py: No USB HID devices found!")
        flash_error()

    print(f"Main.py: Found {len(usb_hid.devices)} HID devices")
    from layouts_manager import *
    layout = "us"
    keycode = keycodes[layout]
    print("Main.py: Keyboard initialized successfully")

    # Test keyboard initialization
    kbd.release_all()
    print("Main.py: Keyboard test successful")


except Exception as e:
    print(f"Main.py: Failed to initialize keyboard: {str(e)}")
    flash_error()

def flash_status():
    """Flash the onboard LED for visual feedback"""
    status_led.value = True
    time.sleep(0.1)
    status_led.value = False

def send_string(text):
    """Send a string as keyboard input"""
    print(f"Sending string: {text}")
    layouts[layout].write(text)

def set_layout(lyt):
    if lyt not in list(layouts.keys()):
        raise Exception(f"Layout '{lyt}' is not a valid layout ({', '.join(list(layouts.keys()))})")
    global layout
    global keycode
    keycode = keycodes[lyt]
    layout = lyt

def press_modifier(parts, modifier_key):
    """Generic function to handle modifier key combinations (GUI, CTRL, SHIFT, ALT)"""
    if len(parts) < 2:
        return
        
    second_part = parts[1].upper()
    modifier_name = modifier_key.upper()
    
    print(f"Processing {modifier_name} command with {second_part}")
    
    # Get the modifier keycode attribute
    modifier_keycode = getattr(keycode, modifier_key.upper())
    
    if second_part == 'SPACE':
        kbd.press(modifier_keycode)
        time.sleep(0.1)
        kbd.press(keycode.SPACE)
        time.sleep(0.1)
        kbd.release_all()
        time.sleep(0.5)  # Add delay after modifier command
    elif second_part == 'CONTROL' or second_part == 'SHIFT' or second_part == 'ALT' or second_part == 'GUI':
        kbd.press(modifier_keycode)
        press_modifier(parts[2:], second_part)
        time.sleep(0.1)
        kbd.release_all()
        time.sleep(0.5)
    elif len(second_part) == 1 and second_part in 'ABCDEFGHIJKLMNOPQRSTUVWXYZ':
        kbd.press(modifier_keycode)
        time.sleep(0.1)
        if hasattr(keycode, second_part):
            kbd.press(getattr(keycode, second_part))
        else:
            # For characters that don't have direct keycode attributes
            layouts[layout].write(second_part.lower())
        time.sleep(0.1)
        kbd.release_all()
        time.sleep(0.5)  # Add delay after modifier command
    
    flash_status()

def interpret_ducky_script(filename):
    """Interpret a DuckyScript file and execute commands"""
    
    try:
        with open(filename, 'r', encoding='utf-8-sig') as file:
            default_delay = 0.2

            for line in file:
                try:
                    line = line.strip()
                    if not line or line.startswith('REM'):
                        continue

                    print(f"Processing line: {line}")
                    parts = line.split(' ', 1)
                    command = parts[0].upper()

                    if command == 'STRING' and len(parts) > 1:
                        print(f"Found STRING command with text: {parts[1]}")
                        # Add delay before typing
                        time.sleep(0.5)
                        send_string(parts[1])
                        flash_status()
                    elif command == 'LAYOUT' and len(parts) > 1:
                        set_layout(parts[1])
                    elif command == 'DELAY' and len(parts) > 1:
                        delay_time = float(parts[1]) / 1000.0
                        print(f"Delaying for {delay_time} seconds")
                        time.sleep(delay_time)
                    elif (command == 'GUI' or command == 'CTRL' or command == 'SHIFT' or command == 'ALT') and len(parts) > 1:
                        press_modifier(parts, command)
                    elif command == 'ENTER':
                        print("Sending ENTER")
                        kbd.press(keycode.ENTER)
                        time.sleep(0.1)
                        kbd.release_all()
                        # Add delay after ENTER
                        time.sleep(0.5)
                        flash_status()
                    elif command == 'TAB':
                        print("Sending TAB")
                        kbd.press(keycode.TAB)
                        time.sleep(0.1)
                        kbd.release_all()
                        # Add delay after TAB
                        time.sleep(0.5)
                        flash_status()
                    elif command == 'ESCAPE':
                        print("Sending ESCAPE")
                        kbd.press(keycode.ESCAPE)
                        time.sleep(0.1)
                        kbd.release_all()
                        # Add delay after ESCAPE
                        time.sleep(0.5)
                        flash_status()
                    elif command == 'SPACE':
                        print("Sending SPACE")
                        kbd.press(keycode.SPACE)
                        time.sleep(0.1)
                        kbd.release_all()
                        # Add delay after SPACE
                        time.sleep(0.5)
                        flash_status()
                    elif command == 'BACKSPACE':
                        print("Sending BACKSPACE")
                        kbd.press(keycode.BACKSPACE)
                        time.sleep(0.1)
                        kbd.release_all()
                        # Add delay after BACKSPACE
                        time.sleep(0.5)
                        flash_status()
                    elif command == 'DELETE':
                        print("Sending DELETE")
                        kbd.press(keycode.DELETE)
                        time.sleep(0.1)
                        kbd.release_all()
                        # Add delay after DELETE
                        time.sleep(0.5)
                        flash_status()
                    elif command[0] == 'F' and command[1:].isdigit():
                        key_num = int(command[1:])
                        if key_num in range(1, 13):
                            print(f"Sending F{key_num}")
                            kbd.press(getattr(keycode, f'F{key_num}'))
                            time.sleep(0.1)
                            kbd.release_all()
                            # Add delay after function key
                            time.sleep(0.5)
                            flash_status()
                    elif command == 'CAPSLOCK':
                        print("Toggling CAPSLOCK")
                        kbd.press(keycode.CAPS_LOCK)
                        time.sleep(0.1)
                        kbd.release_all()
                        # Add delay after CAPSLOCK
                        time.sleep(0.5)
                        flash_status()
                    elif command == 'LEFTARROW':
                        print("Sending LEFTARROW")
                        kbd.press(keycode.LEFT_ARROW)
                        time.sleep(0.1)
                        kbd.release_all()
                        # Add delay after LEFT_ARROW
                        time.sleep(0.5)
                        flash_status()
                    elif command == 'RIGHTARROW':
                        print("Sending RIGHTARROW")
                        kbd.press(keycode.RIGHT_ARROW)
                        time.sleep(0.1)
                        kbd.release_all()
                        # Add delay after RIGHT_ARROW
                        time.sleep(0.5)
                        flash_status()
                    elif command == 'UPARROW':
                        print("Sending UPARROW")
                        kbd.press(keycode.UP_ARROW)
                        time.sleep(0.1)
                        kbd.release_all()
                        # Add delay after UP_ARROW
                        time.sleep(0.5)
                        flash_status()
                    elif command == 'DOWNARROW':
                        print("Sending DOWNARROW")
                        kbd.press(keycode.DOWN_ARROW)
                        time.sleep(0.1)
                        kbd.release_all()
                        # Add delay after DOWN_ARROW
                        time.sleep(0.5)
                        flash_status()
                    elif command == 'HOME':
                        print("Sending HOME")
                        kbd.press(keycode.HOME)
                        time.sleep(0.1)
                        kbd.release_all()
                        # Add delay after HOME
                        time.sleep(0.5)
                        flash_status()
                    elif command == 'END':
                        print("Sending END")
                        kbd.press(keycode.END)
                        time.sleep(0.1)
                        kbd.release_all()
                        # Add delay after END
                        time.sleep(0.5)
                        flash_status()
                    elif command == 'PAGE_UP':
                        print("Sending PAGE_UP")
                        kbd.press(keycode.PAGE_UP)
                        time.sleep(0.1)
                        kbd.release_all()
                        # Add delay after PAGE_UP
                        time.sleep(0.5)
                        flash_status()
                    elif command == 'PAGE_DOWN':
                        print("Sending PAGE_DOWN")
                        kbd.press(keycode.PAGE_DOWN)
                        time.sleep(0.1)
                        kbd.release_all()
                        # Add delay after PAGE_DOWN
                        time.sleep(0.5)
                        flash_status()
                    elif command == 'DEFAULT_DELAY':
                        print("setting DEFAULT_DELAY")
                        default_delay = float(parts[1]) / 1000.0

                    time.sleep(default_delay)  # Default is 0.2 but customizable
                except Exception as line_error:
                    print(f"Error processing line '{line}': {str(line_error)}")
                    continue
    except Exception as e:
        print(f"Error reading file {filename}: {str(e)}")

# Main execution
print("Looking for ducky scripts...")
try:
    # Check for ducks directory in a CircuitPython-compatible way
    try:
        os.listdir('/ducks')
    except OSError:
        print("Creating /ducks directory")
        os.mkdir('/ducks')

    files = os.listdir('/ducks')
    ducky_files = sorted(['/ducks/' + f for f in files if f.endswith('.ducky')])
    print(ducky_files)
    if not ducky_files:
        print("No ducky scripts found")
        # Flash LED pattern to indicate no scripts
        for _ in range(3):
            flash_status()
            time.sleep(0.5)
    else:
        print(f"Found scripts: {ducky_files}")
        for script in ducky_files:
            print(f"Executing {script}")
            flash_status()
            try:
                interpret_ducky_script(script)
                time.sleep(1)
                print(f"Successfully executed {script}")
            except Exception as script_error:
                print(f"Error executing {script}: {str(script_error)}")
                # Flash error pattern but continue with next script
                for _ in range(2):
                    flash_status()
                    time.sleep(0.2)
except Exception as e:
    print(f"Fatal error: {str(e)}")
    while True:
        # Distinct error pattern
        for _ in range(3):
            flash_status()
            time.sleep(0.1)
        time.sleep(1)

print("Execution complete")

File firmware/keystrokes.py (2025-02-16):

import usb.device
from usb.device.keyboard import KeyboardInterface, KeyCode
import time

keyboard = KeyboardInterface()
usb.device.get().init(keyboard, builtin_driver=True)

keypress_delay = 0 

MODIFIER_KEYS = {
    'CTRL': KeyCode.LEFT_CTRL,
    'SHIFT': KeyCode.LEFT_SHIFT,
    'ALT': KeyCode.LEFT_ALT,
    'GUI': KeyCode.LEFT_UI,  
}

SPECIAL_KEYS = {
    'ENTER': KeyCode.ENTER,
    'DELETE': KeyCode.DELETE,
    'ESCAPE': KeyCode.ESCAPE,
    'UP': KeyCode.UP,
    'DOWN': KeyCode.DOWN,
    'LEFT': KeyCode.LEFT,
    'RIGHT': KeyCode.RIGHT,
    'BACKSPACE': KeyCode.BACKSPACE,
    'SPACE': KeyCode.SPACE,
    'TAB': KeyCode.TAB,
    'F1': KeyCode.F1,
    'F2': KeyCode.F2,
    'F3': KeyCode.F3,
    'F4': KeyCode.F4,
    'F5': KeyCode.F5,
    'F6': KeyCode.F6,
    'F7': KeyCode.F7,
    'F8': KeyCode.F8,
    'F9': KeyCode.F9,
    'F10': KeyCode.F10,
    'F11': KeyCode.F11,
    'F12': KeyCode.F12,
}

CHARACTER_TO_KEYCODE = {
    'a': KeyCode.A, 'b': KeyCode.B, 'c': KeyCode.C, 'd': KeyCode.D, 'e': KeyCode.E,
    'f': KeyCode.F, 'g': KeyCode.G, 'h': KeyCode.H, 'i': KeyCode.I, 'j': KeyCode.J,
    'k': KeyCode.K, 'l': KeyCode.L, 'm': KeyCode.M, 'n': KeyCode.N, 'o': KeyCode.O,
    'p': KeyCode.P, 'q': KeyCode.Q, 'r': KeyCode.R, 's': KeyCode.S, 't': KeyCode.T,
    'u': KeyCode.U, 'v': KeyCode.V, 'w': KeyCode.W, 'x': KeyCode.X, 'y': KeyCode.Y,
    'z': KeyCode.Z, ' ': KeyCode.SPACE,
    '0': KeyCode.N0, '1': KeyCode.N1, '2': KeyCode.N2, '3': KeyCode.N3, '4': KeyCode.N4,
    '5': KeyCode.N5, '6': KeyCode.N6, '7': KeyCode.N7, '8': KeyCode.N8, '9': KeyCode.N9,
    '-': KeyCode.MINUS, '=': KeyCode.EQUAL, '[': KeyCode.OPEN_BRACKET, ']': KeyCode.CLOSE_BRACKET,
    '\\': KeyCode.BACKSLASH, ';': KeyCode.SEMICOLON, '\'': KeyCode.QUOTE, '`': KeyCode.GRAVE,
    ',': KeyCode.COMMA, '.': KeyCode.DOT, '/': KeyCode.SLASH, '\n': KeyCode.ENTER, '\t': KeyCode.TAB
}

SHIFT_REQUIRED_CHARACTERS = {
    '!': KeyCode.N1, '@': KeyCode.N2, '#': KeyCode.HASH, '$': KeyCode.N4,
    '%': KeyCode.N5, '^': KeyCode.N6, '&': KeyCode.N7, '*': KeyCode.N8,
    '(': KeyCode.N9, ')': KeyCode.N0, '_': KeyCode.MINUS, '+': KeyCode.EQUAL,
    '{': KeyCode.OPEN_BRACKET, '}': KeyCode.CLOSE_BRACKET, '|': KeyCode.BACKSLASH,
    ':': KeyCode.SEMICOLON, '"': KeyCode.QUOTE, '<': KeyCode.COMMA, '>': KeyCode.DOT,
    '?': KeyCode.SLASH
}

def send_string(text):
    for char in text:
        if char.islower() or char.isdigit() or char in CHARACTER_TO_KEYCODE:
            keycode = CHARACTER_TO_KEYCODE[char.lower()]
            keyboard.send_keys([keycode])
            time.sleep(keypress_delay)
            keyboard.send_keys([]) 
        elif char.isupper():
            keycode = CHARACTER_TO_KEYCODE[char.lower()]
            keyboard.send_keys([MODIFIER_KEYS['SHIFT'], keycode])
            time.sleep(keypress_delay)
            keyboard.send_keys([]) 
        elif char in SHIFT_REQUIRED_CHARACTERS:
            keycode = SHIFT_REQUIRED_CHARACTERS[char]
            keyboard.send_keys([MODIFIER_KEYS['SHIFT'], keycode])
            time.sleep(keypress_delay)
            keyboard.send_keys([]) 
        else:
            print(f"Character '{char}' not found in keycode mapping.")

def interpret_ducky_script(filename):
    with open(filename, 'r') as file:
        lines = file.readlines()

    for line in lines:
        if line.strip().startswith('REM'):
            continue

        parts = line.strip().split()
        command = parts[0].upper()

        if command == 'STRING' and len(parts) > 1:
            send_string(" ".join(parts[1:]))
        elif command in SPECIAL_KEYS:
            keyboard.send_keys([SPECIAL_KEYS[command]])
            time.sleep(keypress_delay)
            keyboard.send_keys([]) 
        elif command == 'DELAY' and len(parts) > 1:
            delay_time = int(parts[1]) / 1000.0
            time.sleep(delay_time)
        elif command in MODIFIER_KEYS:
            modifiers = []
            keycode = None

            for part in parts:
                part_upper = part.upper()
                if part_upper in MODIFIER_KEYS:
                    modifiers.append(MODIFIER_KEYS[part_upper])
                elif part_upper in SPECIAL_KEYS:
                    keycode = SPECIAL_KEYS[part_upper]
                elif part.lower() in CHARACTER_TO_KEYCODE:
                    keycode = CHARACTER_TO_KEYCODE[part.lower()]
                elif part in SHIFT_REQUIRED_CHARACTERS:
                    modifiers.append(MODIFIER_KEYS['SHIFT'])
                    keycode = SHIFT_REQUIRED_CHARACTERS[part]

            if modifiers and keycode:
                keyboard.send_keys(modifiers + [keycode])
                time.sleep(keypress_delay)
                keyboard.send_keys([]) 
            elif modifiers:
                keyboard.send_keys(modifiers)
                time.sleep(keypress_delay)
                keyboard.send_keys([]) 
            else:
                print(f"No key specified for modifiers in command '{line.strip()}'")
        else:
            print(f"Command '{command}' not recognized or not implemented.")

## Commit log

2025-02-03 add pcb folder + files
    [hackducky_v1.kicad_pcb, hackducky_v1.kicad_sch]
2025-02-06 updated schematic, started pcb
    [hackducky_v1.kicad_pcb, hackducky_v1.kicad_sch]
2025-02-16 Update the horrible firmware to Circuit Python !
2025-02-18 Finish the firmware by adding the programming mode and bug fixes
    [boot.py, main.py]
2025-04-23 PCB Done 🥳
    [1054440011.stp, 472192001 v1.step, SKRKAHE020--3DModel-STEP-56544.STEP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]
2025-06-28 Add v7 of the PCB 💀
    [1054440011.stp, 472192001 v1.step, SK6812-EC20.STEP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]
2025-07-05 Just got firmware working by fixing some libraries
    [main.py]
